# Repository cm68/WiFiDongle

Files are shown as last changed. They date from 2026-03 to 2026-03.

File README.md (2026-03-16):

# WiFiDongle
WiFi to serial server for ESP32 with OLED display support.

See https://www.zen-room.org/the-zen-room/serial-to-wifi-plug

## Hardware

- ESP32 dev board
- Optional: SSD1306 or SH1107 128x32 or 128x64 OLED display (I2C, address 0x3C)

## Prerequisites

### PlatformIO (recommended)

Install PlatformIO Core (CLI):

```sh
pip install platformio
```

Or install the VS Code extension: search for "PlatformIO IDE" in the extensions marketplace.

### arduino-cli (alternative)

Install arduino-cli:

```sh
curl -fsSL https://raw.githubusercontent.com/arduino/arduino-cli/master/install.sh | sh
```

Then install the ESP32 board support:

```sh
arduino-cli core update-index
arduino-cli core install esp32:esp32
```

## Building

### With PlatformIO (default)

```sh
make              # compile
make upload       # compile and flash to ESP32
make monitor      # open serial monitor
make upload-monitor  # flash then monitor
make clean        # clean build artifacts
```

### With arduino-cli

```sh
make ino              # compile
make ino-upload       # compile and flash to ESP32
make ino-upload-monitor  # flash then monitor
make ino-clean        # clean build artifacts
```

### Options

Override the serial port or baud rate:

```sh
make upload PORT=/dev/ttyACM0
make monitor BAUD=38400
```

## Configuration

On first boot, the device uses default credentials defined in the source
(`DEFAULT_SSID`, `DEFAULT_PASS`, etc. in `WiFiDongle.ino`).

At runtime, send any character over the serial console to enter the
configuration editor. Changes are saved to EEPROM and persist across reboots.
If WiFi fails to connect within 30 seconds, the editor opens automatically.

### EEPROM format

The EEPROM stores a single ASCII string:

```
"ssid","password",port:baud:flowctl:rx,tx,rts,cts:displayht:displaydrv
```

| Field | Description | Default |
|---|---|---|
| ssid | WiFi network name | yourssid |
| password | WiFi password | yourpassword |
| port | TCP port for the telnet server | 23 |
| baud | UART baud rate for Serial2 | 38400 |
| flowctl | Hardware flow control (0=off, 1=RTS/CTS) | 0 |
| rx | Serial2 RX GPIO pin | 17 |
| tx | Serial2 TX GPIO pin | 16 |
| rts | Serial2 RTS GPIO pin | 5 |
| cts | Serial2 CTS GPIO pin | 4 |
| displayht  | OLED display height (32 or 64) | 32 |
| displaydrv | Display driver (0=SSD1306, 1=SH1107) | 0 |

The format is backward compatible: if older fields are present without the
newer ones (flowctl, pins), defaults are filled in and written back to EEPROM
automatically on boot.

## Custom font

`FreeSans8pt7b.h` was generated from the GNU FreeSans TrueType font using
the Adafruit GFX `fontconvert` tool:

```sh
cd /path/to/Adafruit_GFX_Library/fontconvert
make
./fontconvert /usr/share/fonts/truetype/freefont/FreeSans.ttf 8 > FreeSans8pt7b.h
```

The `fontconvert` source is included in the
[Adafruit GFX Library](https://github.com/adafruit/Adafruit-GFX-Library/tree/master/fontconvert).
It requires the FreeType development library (`libfreetype-dev` on Debian/Ubuntu).

## RS-232 connector and signal direction

The PCB is designed to be stuffed with a **female DB connector**, making the
board a DCE (Data Communications Equipment). This is correct for a device
that is connected to by a DTE (e.g. a PC with a male connector).

A DCE drives two signals:

| Signal | Direction | Description |
|---|---|---|
| TXD | DCE → DTE | Data output (ESP32 TX → connector pin 2) |
| CTS | DCE → DTE | Clear to send (ESP32 RTS → connector pin 8) |

And receives two signals:

| Signal | Direction | Description |
|---|---|---|
| RXD | DTE → DCE | Data input (connector pin 3 → ESP32 RX) |
| RTS | DTE → DCE | Request to send (connector pin 7 → ESP32 CTS) |

Note that the ESP32's RTS output maps to the connector's CTS pin, and the
ESP32's CTS input maps to the connector's RTS pin — the signal names cross
over at the DTE/DCE boundary.

**Important:** If the board is stuffed with a male connector instead, the
TXD/RXD and RTS/CTS pairs will be reversed, since a male connector implies
DTE pinout. The board would then drive the wrong pins.

When hardware flow control is disabled, the ESP32 asserts (drives low) the
RTS pin so that a connected DTE always sees CTS active.

At boot, CTS is held inactive (disasserted) until WiFi connects, then
asserted. This prevents the DTE from sending data before the network is
ready, and also serves as a quick visual check with an RS-232 monitor that
the CTS signal path is working.

## PCB design

The `kicad/` directory contains the KiCad schematic and PCB layout for a
carrier board. It includes a custom ESP32 DevKit V1 footprint and symbol
library. Open `kicad/WiFiDongle.kicad_pro` in KiCad 8 to view or edit.

## Display pin order

Many displays are compatible with the 4-pin header, but some have a different
arrangement of the power pins. The PCB implements the most common pin order:
GND, VCC, SCLK, SDATA. However, one family of 128x64 boards uses VCC, GND,
SCLK, SDATA. This can be corrected by cutting the circuit board traces and
using magnet wire or wire wrap wire to reorder the pins.

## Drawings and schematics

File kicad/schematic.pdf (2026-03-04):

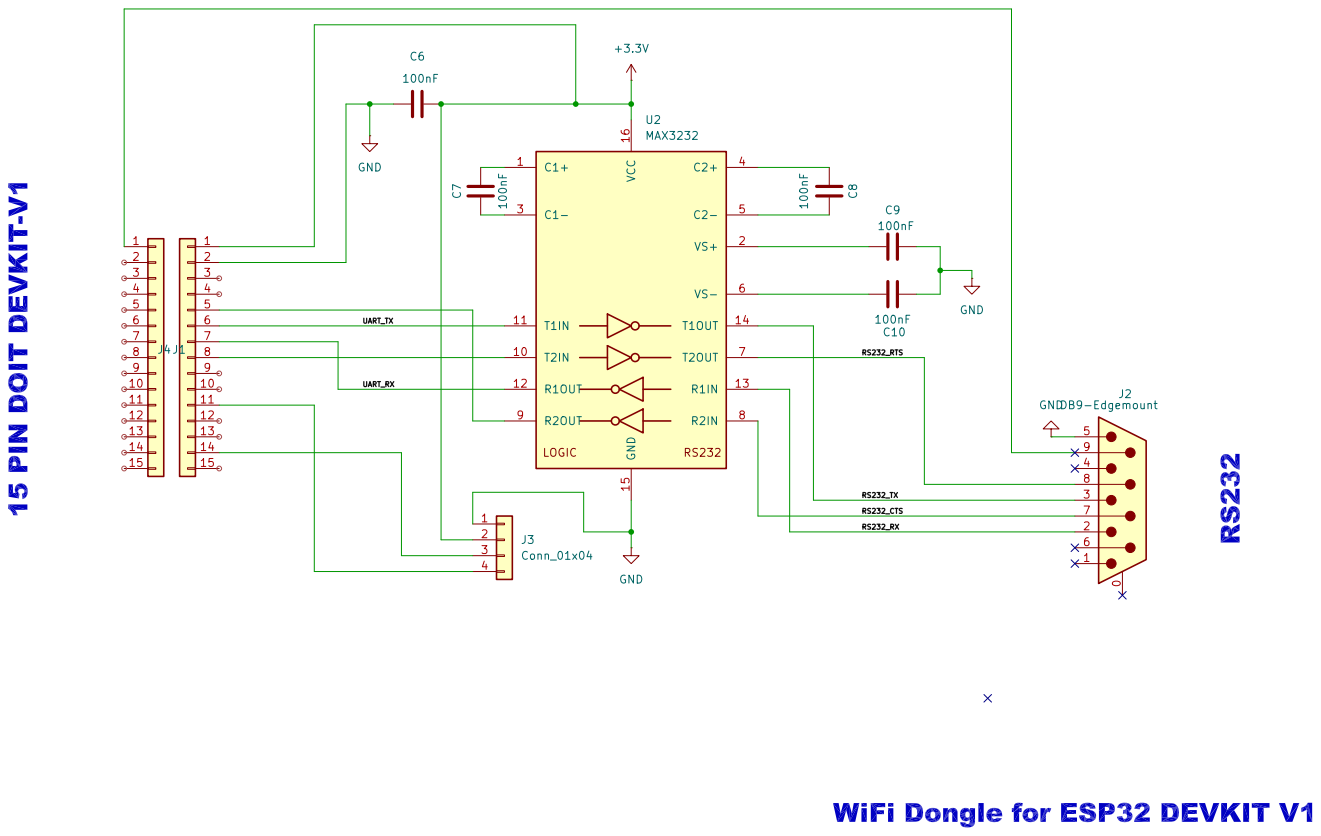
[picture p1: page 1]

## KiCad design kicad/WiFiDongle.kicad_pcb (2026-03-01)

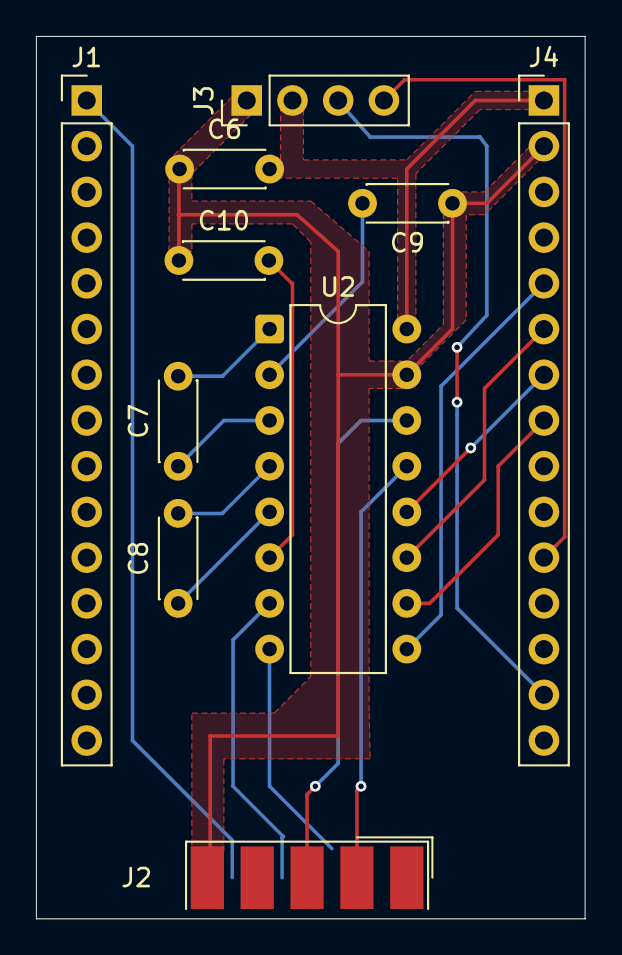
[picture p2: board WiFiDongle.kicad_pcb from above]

Board: 2 copper layers, 30.5 x 49.0 mm, 10 parts (0 on the bottom side), 18 nets.

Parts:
C6, C7, C8, C9, C10: 100nF; C_Disc_D4.3mm_W1.9mm_P5.00mm
J1, J4: Conn_01x15; PinHeader_1x15_P2.54mm_Vertical
J2: DB9-Edgemount; DSUB-9_Socket_EdgeMount_P2.77mm
J3: Conn_01x04; PinHeader_1x04_P2.54mm_Vertical
U2: MAX3232; DIP-16_W7.62mm

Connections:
+3.3V: C6.2, J3.2, J4.1, U2.16 (VCC)
/RS232_CTS: J2.7, U2.8 (R2IN)
/RS232_RTS: J2.8, U2.7 (T2OUT)
/RS232_RX: J2.2, U2.13 (R1IN)
/RS232_TX: J2.3, U2.14 (T1OUT)
/UART_RX: J4.7, U2.12 (R1OUT)
/UART_TX: J4.6, U2.11 (T1IN)
GND: C6.1, C9.1, C10.1, J2.5, J3.1, J4.2, U2.15 (GND)
unnamed: J3.3, J4.14
unnamed: J3.4, J4.11
unnamed: J4.5, U2.9 (R2OUT)
unnamed: J4.8, U2.10 (T2IN)
unnamed: C7.2, U2.1 (C1+)
unnamed: C7.1, U2.3 (C1-)
unnamed: C8.2, U2.4 (C2+)
unnamed: C8.1, U2.5 (C2-)
unnamed: C9.2, U2.2 (VS+)
unnamed: C10.2, U2.6 (VS-)

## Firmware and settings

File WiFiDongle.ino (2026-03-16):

/*
  WiFiTelnetToSerial - Example Transparent UART to Telnet Server for ESP32

  Copyright (c) 2017 Hristo Gochkov. All rights reserved.
  This file is part of the ESP32 WiFi library for Arduino environment.

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
  completely rewritten june 12, 2023 by curt mayer, curt@zen-room.org
  to have configuration in EEPROM with an editor.

*/

/*
 * modified to store baud rate and initial port in EEPROM,
 * and also have a control server to change and read settings
 */
#include <WiFi.h>
#include <WiFiServer.h>
#include <SPI.h>
#include <Wire.h>
#include <EEPROM.h>
#include <driver/uart.h>
#include <Adafruit_GFX.h>
#include <Adafruit_SSD1306.h>
#include <Adafruit_SH110X.h>
#include "FreeSans8pt7b.h"
#define FONT &FreeSans8pt7b

#define DISPLAY_SSD1306 0
#define DISPLAY_SH1107  1

// FreeSans8pt7b: yAdvance=17, ascent=11, '0' is 9px wide, '.' is 4px wide
// zero-filled IP (000.000.000.000) = 12*9 + 3*4 = 120px, fits 128px
#define FONT_HEIGHT 11          // glyph ascent in pixels
#define LINE_SPACING 5          // gap between bottom of one line and top of next
#define LINE_HEIGHT (FONT_HEIGHT + LINE_SPACING)  // 16px per line
// baseline Y for line N (0-based): first baseline at FONT_HEIGHT + 1
#define LINE_Y(n) (FONT_HEIGHT + 1 + (n) * LINE_HEIGHT)

#define SCREEN_ADDRESS 0x3C
Adafruit_GFX *display;          // common base for drawing ops
Adafruit_SSD1306 *disp_ssd1306; // non-NULL if SSD1306
Adafruit_SH1107 *disp_sh1107;   // non-NULL if SH1107

void disp_clear() {
  if (disp_ssd1306) disp_ssd1306->clearDisplay();
  else disp_sh1107->clearDisplay();
}

void disp_show() {
  if (disp_ssd1306) disp_ssd1306->display();
  else disp_sh1107->display();
}

//how many clients should be able to telnet to this ESP32
#define MAX_SRV_CLIENTS 1
String Config;

char ssid[30];
char password[30];

/*
 *
 * modified to store baud rate and initial port in EEPROM,
 * and also allow the UART connection to be used to initialize
 * and edit the EEPROM contents
 * 
 * eeprom contents are a formatted string
 * of the form:
 * "ssid","password",dataport1:baud1:flowctl:rx,tx,rts,cts:displayht:displaydrv
 * where the port and baud rate are integers
 * if the contents are not well formed, we default
 */
#define EEPROM_SIZE 128

//how many clients should be able to telnet to this ESP32
#define MAX_SRV_CLIENTS 1

#define DEFAULT_SSID "yourssid"
#define DEFAULT_PASS "yourpassword"
#define DEFAULT_PORT1 23
#define DEFAULT_BAUD1 38400
#define DEFAULT_FLOW 0
#define DEFAULT_RX 17
#define DEFAULT_TX 16
#define DEFAULT_RTS 5
#define DEFAULT_CTS 4
#define DEFAULT_DISPLAYHT 32
#define DEFAULT_DISPLAYDRV DISPLAY_SSD1306

WiFiServer server;
WiFiClient client;

int port;
int baud;
int flowctl;
int rxpin, txpin, rtspin, ctspin;
int displayht;
int displaydrv;
int needswrite;
unsigned long led_off_time = 0;
#define LED_ON_MS 50
uint8_t last_tx = 0;
uint8_t last_rx = 0;
unsigned long last_display_update = 0;
#define DISPLAY_UPDATE_MS 250

// telnet protocol bytes
#define IAC   0xff
#define DONT  0xfe
#define DO    0xfd
#define WONT  0xfc
#define WILL  0xfb
#define SB    0xfa
#define SE    0xf0
#define BRK   0xf3
#define IP    0xf4  // interrupt process
#define AO    0xf5  // abort output
#define AYT   0xf6  // are you there
#define TNOP  0xf1  // telnet NOP (avoid conflict with ESP32 NOP macro)

#define OPT_ECHO 1
#define OPT_SGA  3

// connection mode: detected from first byte of client traffic
#define MODE_DETECT 0   // waiting for first byte
#define MODE_TELNET 1   // telnet client: IAC parsing + 0xFF escaping active
#define MODE_RAW    2   // raw client: fully transparent, no protocol handling
int conn_mode = MODE_DETECT;

// IAC state machine (only active in MODE_TELNET)
int iac_state = 0;     // 0=data, 1=got IAC, 2=got cmd, 3=subneg, 4=subneg got IAC
uint8_t iac_cmd = 0;   // WILL/WONT/DO/DONT byte, saved for option reply

static const char *iac_cmd_name(uint8_t cmd) {
  switch (cmd) {
    case WILL: return "WILL";
    case WONT: return "WONT";
    case DO:   return "DO";
    case DONT: return "DONT";
    case SB:   return "SB";
    default:   return "??";
  }
}

// send our initial telnet negotiation: character mode + server echo
void telnet_negotiate() {
  uint8_t charmode[] = { IAC, WILL, OPT_SGA, IAC, DO, OPT_SGA, IAC, WILL, OPT_ECHO };
  client.write(charmode, sizeof(charmode));
  Serial.println("telnet: sent WILL SGA, DO SGA, WILL ECHO");
}

// send a telnet option reply
void telnet_reply(uint8_t cmd, uint8_t opt) {
  uint8_t buf[] = { IAC, cmd, opt };
  client.write(buf, 3);
  Serial.printf("telnet: sent %s %d\n", iac_cmd_name(cmd), opt);
}

// process a byte from the client in telnet mode.
// returns 1 if it's a data byte to forward to UART, 0 if consumed by protocol.
int telnet_input(uint8_t c) {
  switch (iac_state) {
  case 0: // normal data
    if (c == IAC) {
      iac_state = 1;
      return 0;
    }
    return 1;

  case 1: // got IAC
    if (c == IAC) {           // escaped 0xFF data byte
      iac_state = 0;
      return 1;
    }
    if (c == SB) {
      Serial.print("telnet: SB ");
      iac_state = 3;
      return 0;
    }
    if (c >= WILL && c <= DONT) {
      iac_cmd = c;
      iac_state = 2;
      return 0;
    }
    // 2-byte commands
    switch (c) {
    case BRK: {
      Serial.println("telnet: BRK");
      // send break: 100 bit-times ensures framing error at any baud rate
      uint8_t brk = 0;
      uart_write_bytes_with_break(2, &brk, 1, 100);
      break;
    }
    case AYT:
      Serial.println("telnet: AYT");
      client.write("\r\n[Yes]\r\n", 9);
      break;
    case IP:  Serial.println("telnet: IP");  break;
    case AO:  Serial.println("telnet: AO");  break;
    case TNOP: break;
    default:
      Serial.printf("telnet: cmd %02x\n", c);
      break;
    }
    iac_state = 0;
    return 0;

  case 2: // option byte following WILL/WONT/DO/DONT
    Serial.printf("telnet: %s %d\n", iac_cmd_name(iac_cmd), c);
    if (c == OPT_SGA || c == OPT_ECHO) {
      // accept SGA and ECHO for character mode
      if (iac_cmd == WILL) telnet_reply(DO, c);
      else if (iac_cmd == DO) telnet_reply(WILL, c);
    } else {
      // refuse everything else
      if (iac_cmd == WILL) telnet_reply(DONT, c);
      else if (iac_cmd == DO) telnet_reply(WONT, c);
    }
    iac_state = 0;
    return 0;

  case 3: // subnegotiation data: consume until IAC SE
    if (c == IAC) {
      iac_state = 4;
    } else {
      Serial.printf("%02x ", c);
    }
    return 0;

  case 4: // subneg: got IAC, expecting SE
    if (c == SE) {
      Serial.println("SE");
      iac_state = 0;
    } else {
      Serial.printf("%02x ", c);
      iac_state = 3;
    }
    return 0;
  }
  iac_state = 0;
  return 1;
}

// write UART data to telnet client, escaping 0xFF as IAC IAC
void telnet_write(uint8_t *buf, size_t len) {
  size_t start = 0;
  for (size_t i = 0; i < len; i++) {
    if (buf[i] == 0xff) {
      // flush data before this byte
      if (i > start) client.write(buf + start, i - start);
      uint8_t iac_iac[] = { IAC, IAC };
      client.write(iac_iac, 2);
      start = i + 1;
    }
  }
  // flush remainder
  if (start < len) client.write(buf + start, len - start);
}

const char *wifistatus(int status) {
  switch (status) {
    case WL_IDLE_STATUS:     return "idle";
    case WL_NO_SSID_AVAIL:   return "SSID not found";
    case WL_CONNECTED:       return "connected";
    case WL_CONNECT_FAILED:  return "connect failed";
    case WL_CONNECTION_LOST: return "connection lost";
    case WL_DISCONNECTED:    return "disconnected";
    default:                 return "unknown";
  }
}

/*
 * this is a somewhat robust state machine parser for the Config string.
 * it reads the eeprom, tries to parse it, and if that fails, parses the
 * default configuration from the above definitions.
 */
void parseeeprom() {
  const char *cbuf;
  char *s, c;
  int p;
  int num;
  int failed = 0;
  needswrite = 0;

  EEPROM.begin(EEPROM_SIZE);
  String data = EEPROM.readString(0);
  EEPROM.end();

again:
  if (failed || (data.length() == 0)) {
    Config = "\"";
    Config += DEFAULT_SSID;
    Config += "\",\"";
    Config += DEFAULT_PASS;
    Config += "\",";
    Config += DEFAULT_PORT1;
    Config += ":";
    Config += DEFAULT_BAUD1;
    Config += ":";
    Config += DEFAULT_FLOW;
    Config += ":";
    Config += DEFAULT_RX;
    Config += ",";
    Config += DEFAULT_TX;
    Config += ",";
    Config += DEFAULT_RTS;
    Config += ",";
    Config += DEFAULT_CTS;
    Config += ":";
    Config += DEFAULT_DISPLAYHT;
    Config += ":";
    Config += DEFAULT_DISPLAYDRV;
    Config += "\n";
  } else {
    Config = data;
  }
  Serial.println("using configuration: " + Config);
  cbuf = Config.c_str();
  // Serial.printf("string form: %s\n", cbuf);
  p = 0;
  while ((c = *cbuf++)) {
    // Serial.printf("state: %d char: 0x%x num: %d\n", p, c, num);
    switch (p) {
      case 0:
        if (c != '\"') goto fail;
        p++;
        s = ssid;
        break;
      case 1:
        if (c == '"') {
          *s = '\0';
          p++;
        } else {
          *s++ = c;
        }
        break;
      case 2:
        if (c != ',') goto fail;
        p++;
        break;
      case 3:
        if (c != '\"') goto fail;
        p++;
        s = password;
        break;
      case 4:
        if (c == '"') {
          *s = '\0';
          p++;
        } else {
          *s++ = c;
        }
        break;
      case 5:
        if (c != ',') goto fail;
        p++;
        num = 0;
        break;
      case 6:
        if (c == ':') {
          port = num;
          p++;
          num = 0;
        } else {
          if ((c < '0') || (c > '9')) goto fail;
          num = (num * 10) + (c - '0');
        }
        break;
      case 7:
        if (c == '\n') {
          baud = num;
          flowctl = 0;
          rxpin = DEFAULT_RX; txpin = DEFAULT_TX;
          rtspin = DEFAULT_RTS; ctspin = DEFAULT_CTS;
          displayht = DEFAULT_DISPLAYHT;
          displaydrv = DEFAULT_DISPLAYDRV;
          needswrite = 1;
          p = 15;
        } else if (c == ':') {
          baud = num;
          p++;
          num = 0;
        } else {
          if ((c < '0') || (c > '9')) goto fail;
          num = (num * 10) + (c - '0');
        }
        break;
      case 8:
        if (c == '\n') {
          flowctl = num;
          rxpin = DEFAULT_RX; txpin = DEFAULT_TX;
          rtspin = DEFAULT_RTS; ctspin = DEFAULT_CTS;
          displayht = DEFAULT_DISPLAYHT;
          displaydrv = DEFAULT_DISPLAYDRV;
          needswrite = 1;
          p = 15;
        } else if (c == ':') {
          flowctl = num;
          p++;
          num = 0;
        } else {
          if ((c < '0') || (c > '9')) goto fail;
          num = (num * 10) + (c - '0');
        }
        break;
      case 9:
        if (c == ',') {
          rxpin = num;
          p++;
          num = 0;
        } else {
          if ((c < '0') || (c > '9')) goto fail;
          num = (num * 10) + (c - '0');
        }
        break;
      case 10:
        if (c == ',') {
          txpin = num;
          p++;
          num = 0;
        } else {
          if ((c < '0') || (c > '9')) goto fail;
          num = (num * 10) + (c - '0');
        }
        break;
      case 11:
        if (c == ',') {
          rtspin = num;
          p++;
          num = 0;
        } else {
          if ((c < '0') || (c > '9')) goto fail;
          num = (num * 10) + (c - '0');
        }
        break;
      case 12:
        if (c == '\n') {
          ctspin = num;
          displayht = DEFAULT_DISPLAYHT;
          displaydrv = DEFAULT_DISPLAYDRV;
          needswrite = 1;
          p = 15;
        } else if (c == ':') {
          ctspin = num;
          p++;
          num = 0;
        } else {
          if ((c < '0') || (c > '9')) goto fail;
          num = (num * 10) + (c - '0');
        }
        break;
      case 13:
        if (c == '\n') {
          displayht = num;
          displaydrv = DEFAULT_DISPLAYDRV;
          needswrite = 1;
          p = 15;
        } else if (c == ':') {
          displayht = num;
          p++;
          num = 0;
        } else {
          if ((c < '0') || (c > '9')) goto fail;
          num = (num * 10) + (c - '0');
        }
        break;
      case 14:
        if (c == '\n') {
          displaydrv = num;
          p++;
        } else {
          if ((c < '0') || (c > '9')) goto fail;
          num = (num * 10) + (c - '0');
        }
        break;
      default:
        Serial.println("long parse error");
        goto fail;
    }
  }
  return;

fail:
  if (failed++) {
    Serial.println("parse of default failed");
    return;
  }
  goto again;
}

String buildconfig() {
  String c = "\"";
  c += ssid;
  c += "\",\"";
  c += password;
  c += "\",";
  c += String(port);
  c += ":";
  c += String(baud);
  c += ":";
  c += String(flowctl);
  c += ":";
  c += String(rxpin);
  c += ",";
  c += String(txpin);
  c += ",";
  c += String(rtspin);
  c += ",";
  c += String(ctspin);
  c += ":";
  c += String(displayht);
  c += ":";
  c += String(displaydrv);
  c += "\n";
  return c;
}

void writeeeprom(String newconfig) {
  Serial.println("writing eeprom with " + newconfig);
  EEPROM.begin(EEPROM_SIZE);
  EEPROM.writeString(0, newconfig);
  EEPROM.commit();
  EEPROM.end();
  Config = newconfig;
  Serial.println("done");
}

void editstr(const char *prompt, char *buf) {
  unsigned char c;
  int cursor = strlen(buf);

  Serial.printf("%s: %s", prompt, buf);
  while (1) {
    if (Serial.available() <= 0) continue;
    c = Serial.read();

    if (c == '\r') {
      Serial.printf("\r\n");
      return;
    }
    switch (c) {
      case 0x7f:
      case 0x8:
        if (cursor != 0) {
          Serial.printf("\b \b");
          buf[--cursor] = '\0';
        }
        break;
      case 0x0d:
        return;
      default:
        if ((c < ' ') || (c > 0x80)) {
          break;
        }
        buf[cursor++] = c;
        Serial.printf("%c", c);
    }
  }
}

void editnum(const char *prompt, int *valp) {
  char buf[20];
  sprintf(buf, "%d", *valp);
  editstr(prompt, buf);
  *valp = atoi(buf);
}

int editeeprom() {
  String Newconfig;

  Serial.println("Scanning for WiFi networks...");
  int n = WiFi.scanNetworks();
  if (n == 0) {
    Serial.println("  No networks found");
  } else {
    Serial.printf("  %d network(s) found:\n", n);
    for (int i = 0; i < n; i++) {
      Serial.printf("  %2d: %-32s  %ddBm  %s\n", i + 1,
        WiFi.SSID(i).c_str(), WiFi.RSSI(i),
        WiFi.encryptionType(i) == WIFI_AUTH_OPEN ? "open" : "encrypted");
    }
  }
  WiFi.scanDelete();
  Serial.println();

  editstr("ssid", ssid);
  editstr("password", password);
  editnum("port1", &port);
  editnum("baud1", &baud);
  editnum("flowctl (0=off, 1=rtscts)", &flowctl);
  editnum("rx pin", &rxpin);
  editnum("tx pin", &txpin);
  editnum("rts pin", &rtspin);
  editnum("cts pin", &ctspin);
  editnum("display height (32 or 64)", &displayht);
  editnum("display driver (0=SSD1306, 1=SH1107)", &displaydrv);

  Newconfig = buildconfig();
  if (Config.equals(Newconfig)) {
    Serial.println("no difference");
    return 0;
  }
  writeeeprom(Newconfig);
  return 1;
}

#define LED 2

int display_present = 1;

void update_traffic_display() {
  if (!display_present) return;
  if (millis() - last_display_update < DISPLAY_UPDATE_MS) return;
  last_display_update = millis();

  display->setFont(FONT);
  display->setTextSize(1);
  display->setTextWrap(false);
  display->setTextColor(1);

  // flow control indicator at last char position on line 1
  char fc = ' ';
  if (flowctl) {
    int cts_blocked = digitalRead(ctspin);  // HIGH = remote not accepting our data
    int rts_full = digitalRead(rtspin);     // HIGH = we deasserted RTS (buffer full)
    if (cts_blocked && rts_full) fc = 'X';
    else if (cts_blocked) fc = 'B';
    else if (rts_full) fc = 'F';
  }
  display->fillRect(119, LINE_Y(1) - FONT_HEIGHT, 9, LINE_HEIGHT, 0);
  display->setCursor(119, LINE_Y(1));
  display->print(fc);

  if (displayht > 32) {
    // clear lines 2-3 (bottom half of 64px display) and redraw
    display->fillRect(0, LINE_Y(2) - FONT_HEIGHT, 128, 2 * LINE_HEIGHT, 0);
    char tc = (last_tx >= ' ' && last_tx < 0x7f) ? last_tx : '.';
    char rc = (last_rx >= ' ' && last_rx < 0x7f) ? last_rx : '.';
    display->setCursor(0, LINE_Y(2));
    display->printf("tx %c %02x", tc, last_tx);
    display->setCursor(0, LINE_Y(3));
    display->printf("rx %c %02x", rc, last_rx);
  }

  disp_show();
}

void setup() {
  
  pinMode(LED, OUTPUT);

  Serial.begin(115200);
  Serial.println("\nConnecting");

  parseeeprom();
  Serial.printf("  pins: rx=%d tx=%d rts=%d cts=%d\n", rxpin, txpin, rtspin, ctspin);
  if (needswrite) {
    writeeeprom(buildconfig());
    needswrite = 0;
  }

  // disassert RTS (DTE sees CTS inactive) until network is ready
  pinMode(rtspin, OUTPUT);
  digitalWrite(rtspin, HIGH);

  bool display_ok;
  disp_ssd1306 = NULL;
  disp_sh1107 = NULL;
  if (displaydrv == DISPLAY_SH1107) {
    disp_sh1107 = new Adafruit_SH1107(displayht, 128, &Wire, -1);
    display = disp_sh1107;
    display_ok = disp_sh1107->begin(SCREEN_ADDRESS, true);
  } else {
    disp_ssd1306 = new Adafruit_SSD1306(128, displayht, &Wire, -1);
    display = disp_ssd1306;
    display_ok = disp_ssd1306->begin(SSD1306_SWITCHCAPVCC, SCREEN_ADDRESS);
  }
  if (!display_ok) {
    Serial.printf("%s init failed\n", displaydrv == DISPLAY_SH1107 ? "SH1107" : "SSD1306");
    display_present = 0;
  } else {
    if (displaydrv == DISPLAY_SH1107)
      display->setRotation(3);
    disp_clear();
    display->setFont(FONT);
    display->setTextSize(1);
    display->setTextWrap(false);
    display->setTextColor(1);
    display->setCursor(0, LINE_Y(0));
    display->println(ssid);
    display->setCursor(0, LINE_Y(1));
    display->printf("%d:%d", port, baud);
    disp_show();
  }

  WiFi.mode(WIFI_STA);
  WiFi.begin(ssid, password);

  Serial.println("Connecting Wifi ");
  for (int loops = 30; loops > 0; loops--) {
    if (WiFi.status() == WL_CONNECTED) {
      Serial.println("");
      Serial.print("WiFi connected ");
      Serial.print("IP address: ");
      Serial.println(WiFi.localIP());

      if (display_present) {
        disp_clear();
        display->setFont(FONT);
        display->setTextSize(1);
        display->setTextWrap(false);
        display->setTextColor(1);
        display->setCursor(0, LINE_Y(0));
        display->println(WiFi.localIP());
        display->setCursor(0, LINE_Y(1));
        display->printf("%d:%d", port, baud);
        disp_show();
      }
      break;
    } else {
      Serial.printf("%d (%s)\n", loops, wifistatus(WiFi.status()));
      delay(1000);
    }
  }
  if (WiFi.status() != WL_CONNECTED) {
    Serial.printf("WiFi connect failed: %s\n", wifistatus(WiFi.status()));
    delay(1000);
    (void)editeeprom();
    ESP.restart();
  }

  //start UART and the server
  Serial2.begin(baud);
  Serial2.setPins(rxpin, txpin, ctspin, rtspin);
  if (flowctl) {
    Serial2.setHwFlowCtrlMode(UART_HW_FLOWCTRL_CTS_RTS, 64);
    Serial.println("Hardware flow control enabled");
  } else {
    pinMode(rtspin, OUTPUT);
    digitalWrite(rtspin, LOW);  // assert RTS: always ready to receive
  }

  server.begin(port);
  server.setNoDelay(true);

  Serial.print("Ready! Use ");
  Serial.print(WiFi.localIP());
  Serial.println(" to connect on port " + String(port));
}

void loop() {
    if (Serial.available() > 0) {
    Serial.println("Edit configuration");
    (void)Serial.read();
    if (editeeprom()) {
      ESP.restart();    
    }
  }
  
  if (WiFi.status() == WL_CONNECTED) {
    if (server.hasClient()) {
      client = server.available();
      if (!client) Serial.println("available broken");
      conn_mode = MODE_DETECT;
      iac_state = 0;
      Serial.print("client connected from ");
      Serial.println(client.remoteIP());
    }

    if (client) {
      if (!client.connected()) {
        Serial.println("client disconnected");
        client.stop();
        client = 0;
      } else {
        if (client.available()) {
          uint8_t c = client.read();

          // first byte from client determines protocol
          if (conn_mode == MODE_DETECT) {
            if (c == IAC) {
              conn_mode = MODE_TELNET;
              Serial.println("telnet client detected");
              telnet_negotiate();
              iac_state = 1;  // we already consumed the IAC
              goto skip_data;
            } else {
              conn_mode = MODE_RAW;
              Serial.println("raw client detected");
            }
          }

          if (conn_mode == MODE_TELNET) {
            if (!telnet_input(c)) goto skip_data;
          }

          digitalWrite(LED, HIGH);
          led_off_time = millis() + LED_ON_MS;
          last_tx = c;
          Serial2.write(c);
          skip_data: ;
        }

        if (Serial2.available()) {
          digitalWrite(LED, HIGH);
          led_off_time = millis() + LED_ON_MS;
          size_t len = Serial2.available();
          uint8_t sbuf[len];
          Serial2.readBytes(sbuf, len);
          if (conn_mode == MODE_TELNET) {
            telnet_write(sbuf, len);
          } else {
            client.write(sbuf, len);
          }
          last_rx = sbuf[len - 1];
        }
        update_traffic_display();
      }
    }
  } else {
    Serial.printf("WiFi not connected: %s\n", wifistatus(WiFi.status()));
    if (client) {
      client.stop();
      client = 0;
    }
    delay(1000);
  }
  if (led_off_time && millis() >= led_off_time) {
    digitalWrite(LED, LOW);
    led_off_time = 0;
  }
}

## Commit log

2026-02-28 Add OLED display support, PlatformIO build, and build instructions
    - Add SSD1306 OLED display: shows port:baud and SSID/IP
    - Improve EEPROM handling with scoped begin/end
    - Increase WiFi connect timeout to 30 seconds
    - Add WiFi.status() diagnostics to serial output
    - Add Makefile with PlatformIO and arduino-cli targets
    - Add platformio.ini for ESP32 dev board
    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
2026-03-01 Add configurable UART pins, flow control, KiCad PCB design
    - Add EEPROM fields for UART pin assignment (rx, tx, rts, cts)
    - Auto-upgrade old EEPROM format with default pins on boot
    - Add hardware flow control (RTS/CTS) as EEPROM setting
    - Human-readable WiFi status messages in serial output
    - Fix const-correctness warnings in editstr/editnum
    - Add KiCad schematic and PCB layout for carrier board
    - Update README with EEPROM format docs and PCB section
    [WiFiDongle.kicad_pcb, WiFiDongle.kicad_sch]
2026-03-04 added schematic
2026-03-12 Add configurable display height for 128x32 and 128x64 OLED support
    Display height is now stored in EEPROM config and editable at runtime.
    The SSD1306 driver is allocated dynamically after config is parsed.
    On 128x64 displays, port:baud is shown below the IP instead of at
    the screen bottom.
2026-03-12 Show last TX/RX character on display instead of byte counts
    Display lines 3-4 on 128x64 now show the last character sent/received
    as a sanitized printable character and hex value.
2026-03-13 Switch to generated FreeSans8pt font, support 128x64 display
    Generated FreeSans8pt7b.h using Adafruit fontconvert from FreeSans.ttf.
    Proportional glyphs fit full IPs within 128px width. Ascent-only line
    packing (11px + 5px gap = 16px) fits 4 lines in 64px. Lines 3-4 on
    128x64 show last TX/RX character and hex value. Updated README with
    font generation instructions and displayht config field.
2026-03-13 Add telnet protocol handling with auto-detect and FreeSans8pt font
    Auto-detect telnet vs raw clients from first byte. In telnet mode:
    negotiate character mode (SGA + ECHO), refuse all other options,
    handle IAC BRK as UART break, escape 0xFF from UART as IAC IAC.
    Raw clients get fully transparent passthrough.
    Switched OLED to generated FreeSans8pt7b font with parameterized
    line layout. Updated README with displayht config and font generation.
2026-03-14 Swap default RX/TX pins and show flow control state on display
    Default pins changed to RX=17, TX=16. Display now shows a flow
    control indicator at the end of line 2: B (CTS blocked), F (RTS
    deasserted/full), X (both), or blank (disabled/idle). Works on
    both 32px and 64px displays.
    [WiFiDongle.kicad_sch]
2026-03-14 Disassert CTS at boot until WiFi connects, document RS-232 pinout
    RTS is driven high (CTS inactive to DTE) during startup so the DTE
    won't send data before the network is ready. Also serves as a visual
    test of the CTS signal path with an RS-232 monitor. Added README
    section documenting DCE signal direction and male connector warning.
    [WiFiDongle.ino]
2026-03-15 Document display pin order and workaround for swapped power pins
2026-03-16 Add SH1107 display driver support with EEPROM config selection
